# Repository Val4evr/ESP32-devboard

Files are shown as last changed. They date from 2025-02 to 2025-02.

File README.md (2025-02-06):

# ESP32-devboard

I made this ESP-32 Development board to learn KiCad. It is heavilly based on the [ESP32-DevKit C](https://www.espressif.com/en/products/devkits/esp32-devkitc/resources) reference implementation, but with the redundant micro USB port replaced with USB-C. Here's a ray-traced KiCad render:

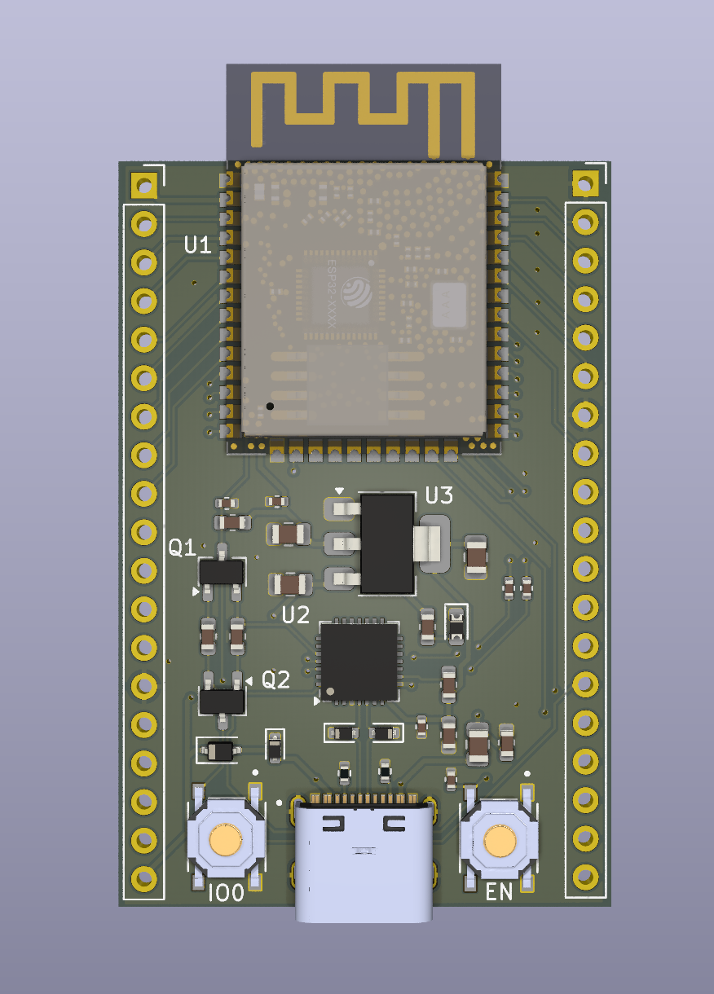
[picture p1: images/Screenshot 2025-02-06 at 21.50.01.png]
Ray-traced render of the assembled Devboard


# Usage
This repo comes with the footprints, 3D models and everything needed to reproduce the renders. Also, this KiCad project uses the [KiKit](https://github.com/yaqwsx/KiKit) extension to create the below panelization in a format compatible with the [JLCPCB PCBA service](https://jlcpcb.com/smt-assembly). 

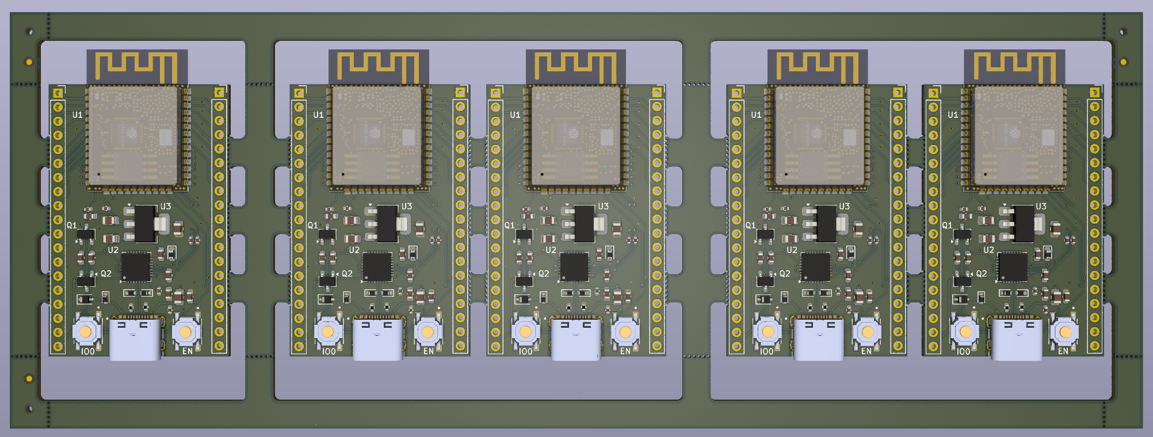
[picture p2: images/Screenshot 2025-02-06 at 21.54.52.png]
Ray-traced render of the assembled Devboards, panelized


The resultant production files are [here](https://github.com/Val4evr/ESP32-devboard/blob/main/ESP32_panelized_outputgerbers.zip). If you want to edit the design you will have to re-create the panel and gerbers for production:
1. [Setup KiKit](https://yaqwsx.github.io/KiKit/latest/installation/intro/)
2. Open an empty KiCad pcbnew instance
3. Click on the KiKit icon to open the GUI.
4. Select the updated pcb design and output directory (I used `/panelized`) 
5. Import my KiKit [JSON config](https://github.com/Val4evr/ESP32-devboard/blob/main/panelized/kikit_config.json)
6. Panelize!

If you then decide it's good enough for production, run the following snippet to get the gerbers, specifying the path to the panel. 
```
kikit fab jlcpcb --nametemplate "ESP32_panelized_output{}" --no-drc --assembly --schematic <path to schematic file> <path to PCB file> <path to output directory>
```

This will produce gerber, drill and position files for JLC PCB. 

# Previous revisions:
The PCB did not work on first try because of two misconfigured 0ohm DNP resistors on the USB serial traces. As a result I had to solder two strands of solder wick directly to the serial converter chip and ESP32, and hold them in place with copious quantities of tape. 

All Photos - 1 of 1

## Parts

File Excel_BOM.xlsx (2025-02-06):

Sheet: BOM
Simple Components:
Type | Comment / Value | Designator | Footprint / Package | JLCPCB Part# | Library Type (Ex/Exp/Bc) | Notes:
Capacitor | 4.7uF/16v(10%) | C1 | 0603 | C19666 | Basic
Capacitor | 0.1uF/50V(10%) | C2, C4, C5, C7, C9 | 0402 | C307331 | Basic
Capacitor | 22uF/10V(20%) | C3, C6, C8 | 0805 | C45783 | Basic
Resistor | 10K(5%) | R1, R2 | 1206 | C17902 | Basic
Resistor | 22K(5%) | R3 | 0805 | C17560 | Basic | Changed from 22.1K
Resistor | 47K(5%) | R4 | 0603 | C25819 | Basic | Changed from 44.5K.
Resistor | 2K(5%) | R5, R10 | 0603 | C22975 | Basic
Resistor | 0R (5%) | R6, R7 | 0402 | C17168 | Basic | 0 ohm resistor. Verify is required.
Resistor | 10K(1%) | R8, R9, R11, R12, R13, R14 | 0603 | C25804 | Basic | R8 is marked as NC. Verify.
Transistor | SS8050-G | Q1, Q2 | SOT23 | C164885 | External
ESD Protection | LESD5D5.OCT1G | D2, D3, D4 | SOD-523 | C383211 | External
Diode | BAT760-7 | D5 | SOD-323 | C124187 | External
LED | RED LED | D1 | 0603 | C2286 | Basic
Voltage Regulator | AMS1117-3.3 | U3 | SOT-223-3 | C6186 | Basic
Switch | TS-1187A-B-A-B | SW1, SW2 | SMD | C318884 | External
Complex Components:
Type | Comment / Value | Designator | Footprint / Package | JLCPCB Part# | Library Type (Ex/Exp/Bc) | Notes: | e
USB-C | 16Pin USB-C Connector | J3 | SMD | C2988369 | External
ESP32 | ESP32-WROOM-32E-N4 | U1 | SMD,18x25.5mm | C701341 | External
USB-UART | CP2102N-A02 | U2 | QFN-28-EP(5x5) | C964632 | External

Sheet: Formated BOM
Type | Comment | Designator | Footprint | JLCPCB Part#
Capacitor | 4.7uF/16v(10%) | C1 | 0603 | C19666
Capacitor | 0.1uF/50V(10%) | C2, C4, C5, C7, C9 | 0402 | C307331
Capacitor | 22uF/10V(20%) | C3, C6, C8 | 0805 | C45783
Resistor | 22K(5%) | R3 | 0805 | C17560
Resistor | 47K(5%) | R4 | 0603 | C25819
Resistor | 2K(5%) | R5, R10 | 0603 | C22975
Resistor | 0R (5%) | R6, R7 | 0402 | C17168 | e
Resistor | 10K(1%) | R1, R2, R8, R9, R11, R12, R13, R14 | 0603 | C25804
Transistor | SS8050-G | Q1, Q2 | SOT23 | C164885
ESD Protection | LESD5D5.OCT1G | D2, D3, D4 | SOD-523 | C383211
Diode | BAT760-7 | D5 | SOD-323 | C124187
LED | RED LED | D1 | 0603 | C2286
Voltage Regulator | AMS1117-3.3 | U3 | SOT-223-3 | C6186
Switch | TS-1187A-B-A-B | SW1, SW2 | SMD | C318884
USB-C | 16Pin USB-C Connector | J3 | SMD | C2988369
ESP32 | ESP32-WROOM-32E-N4 | U1 | SMD,18x25.5mm | C701341
USB-UART | CP2102N-A02 | U2 | QFN-28-EP(5x5) | C964632

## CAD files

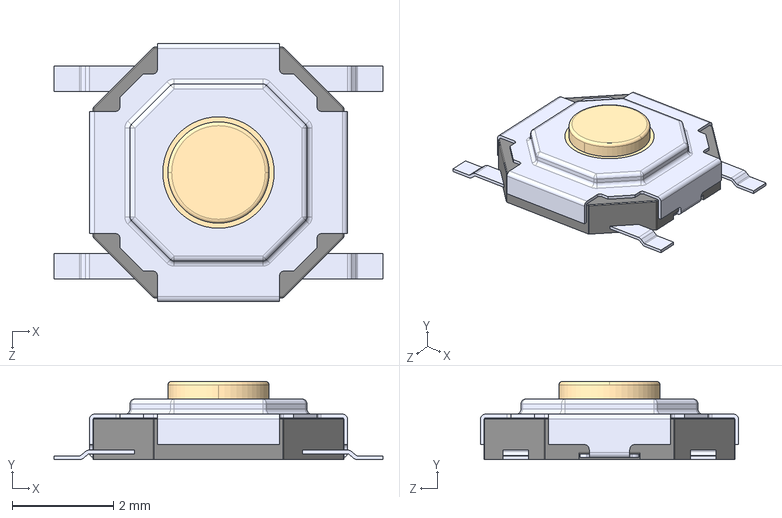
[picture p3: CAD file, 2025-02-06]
3D_models/TS-1187A-B-A-B--3DModel-STEP-56544.STEP
6.50 x 1.55 x 5.10 mm

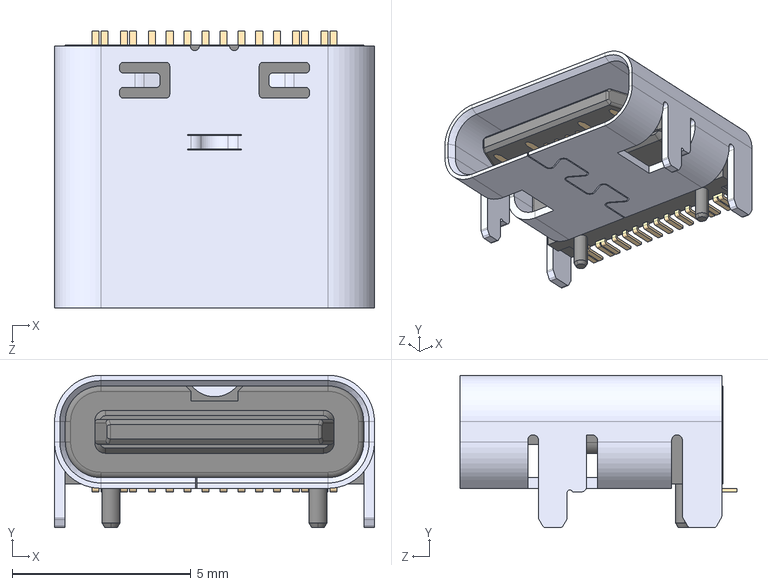
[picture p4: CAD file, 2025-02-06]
3D_models/CSP-USC16-TR--3DModel-STEP-468060.STEP
8.94 x 4.26 x 7.75 mm

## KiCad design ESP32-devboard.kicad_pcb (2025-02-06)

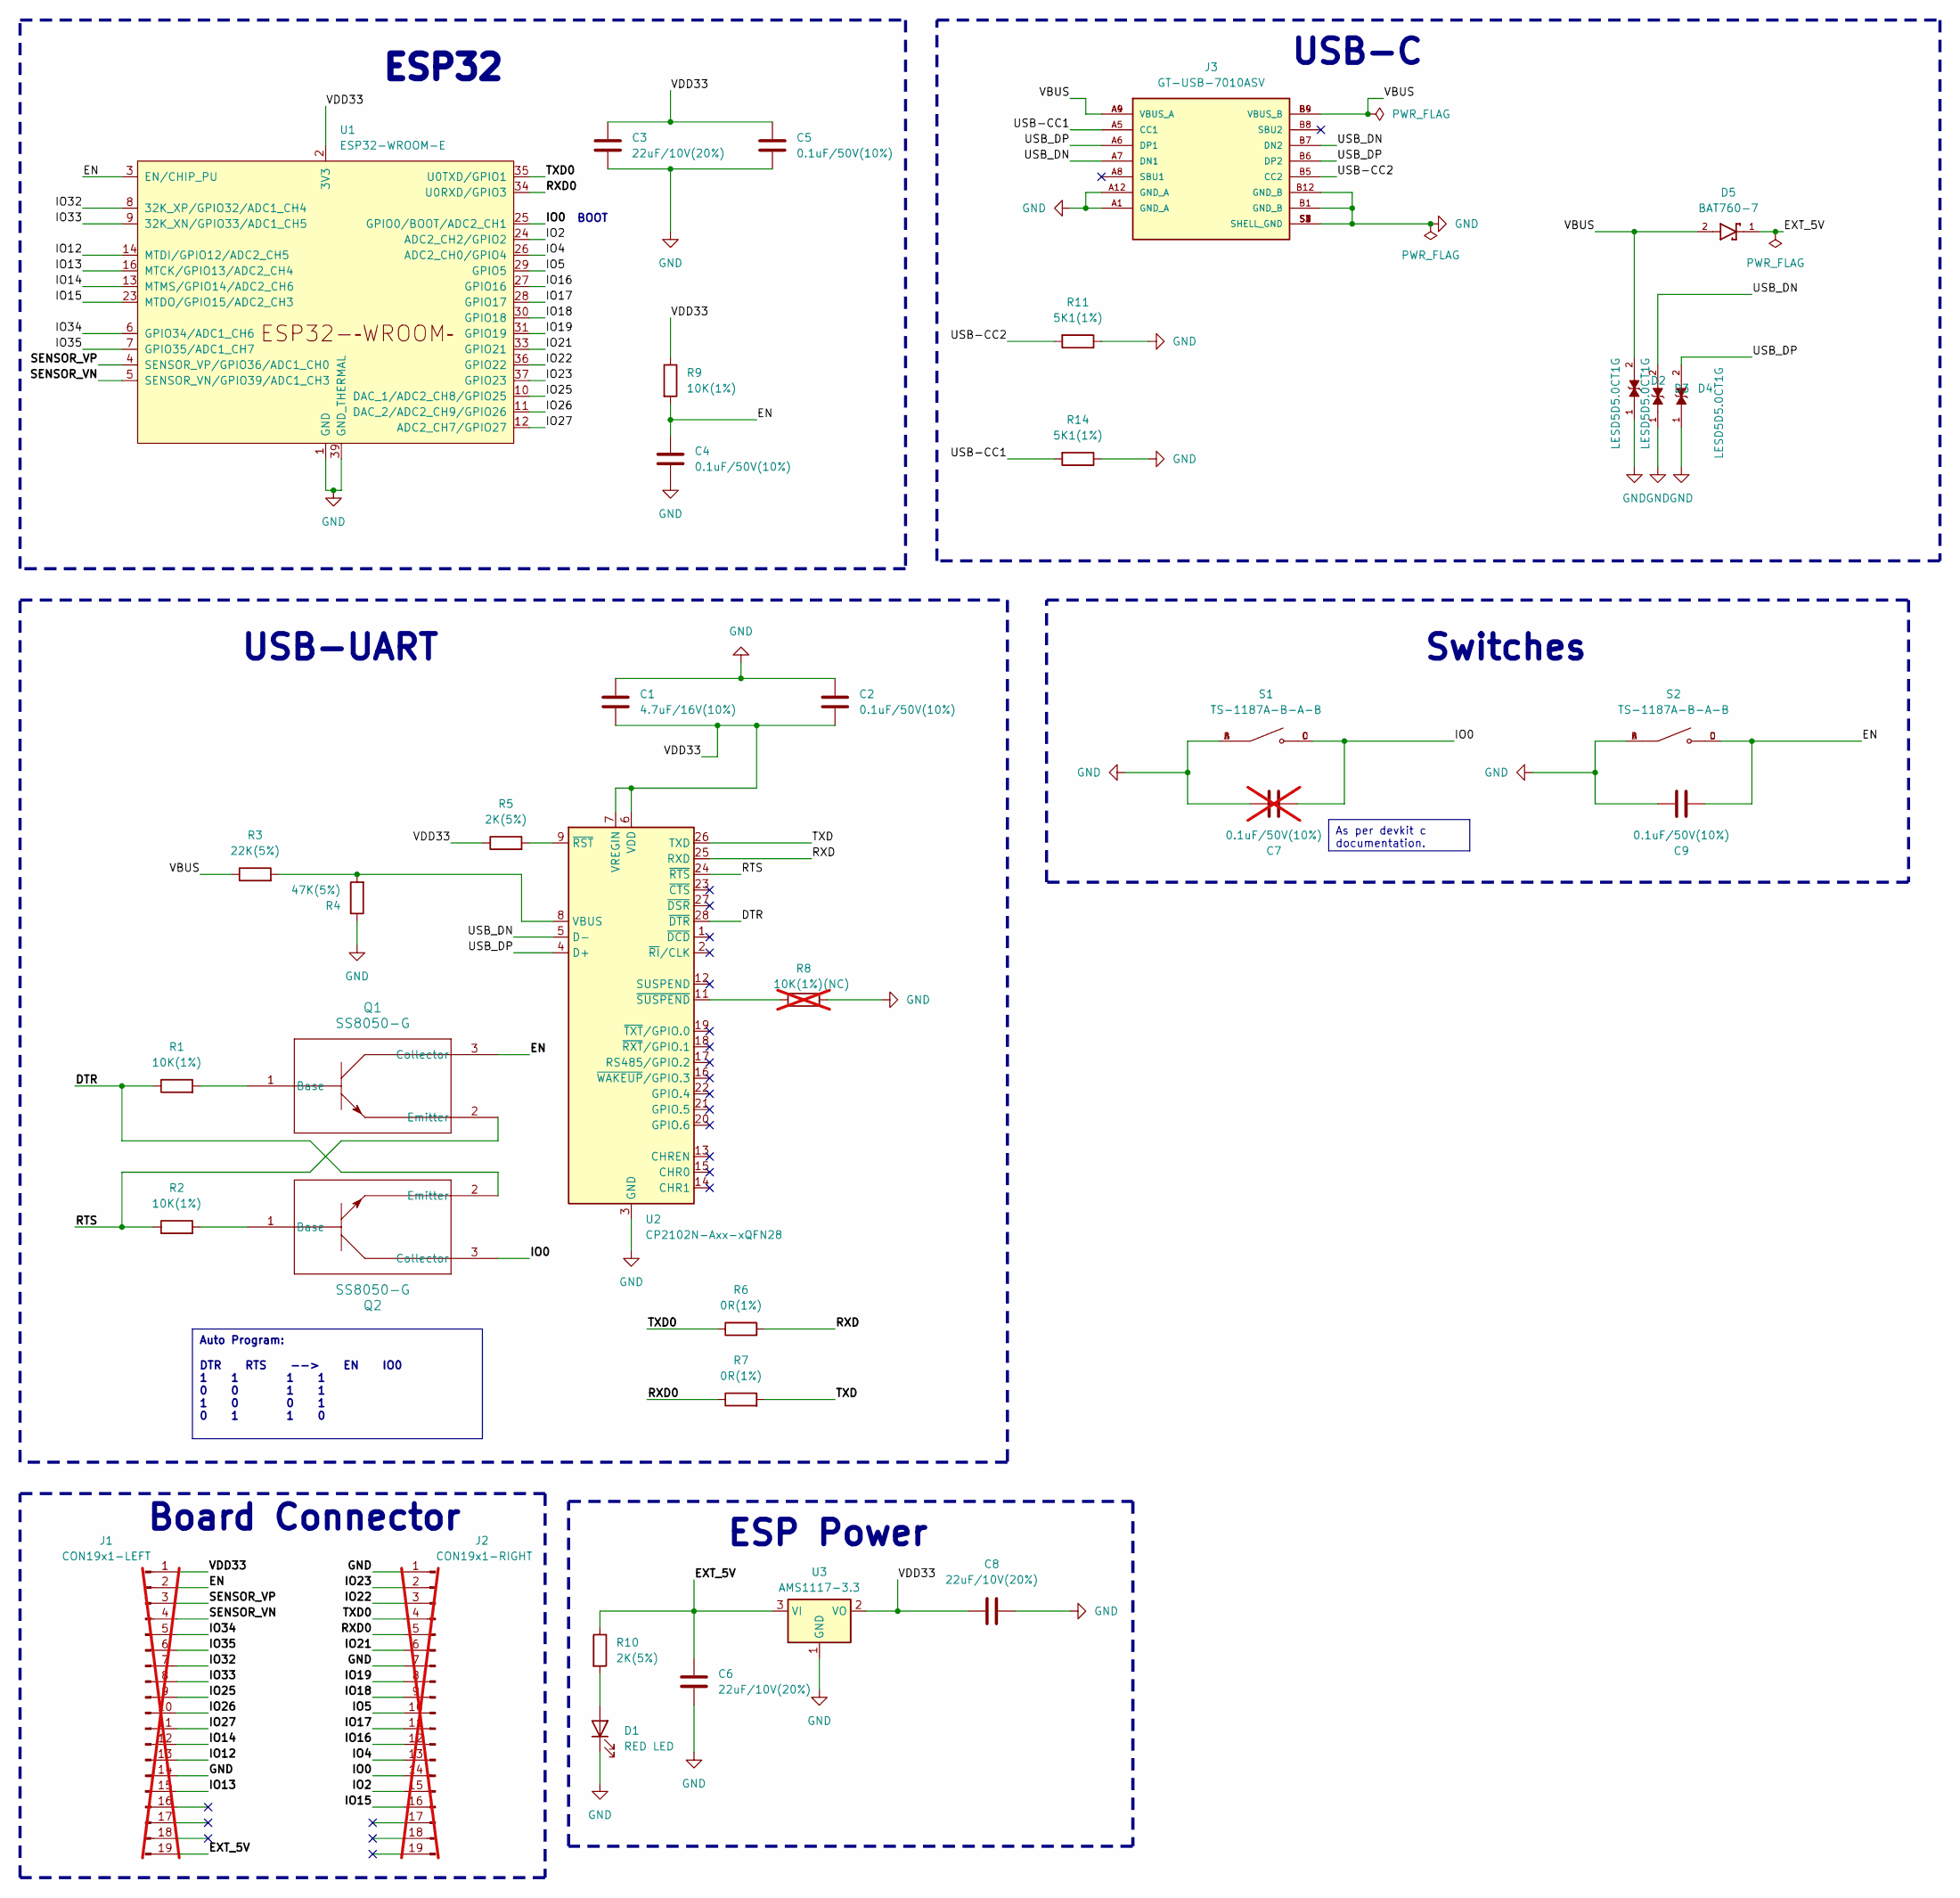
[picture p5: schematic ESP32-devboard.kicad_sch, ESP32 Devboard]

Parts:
C1: 4.7uF/16V(10%); C_0603_1608Metric; LCSC C19666
C2, C4, C5, C9: 0.1uF/50V(10%); C_0402_1005Metric; LCSC C307331
C3, C6, C8: 22uF/10V(20%); C_0805_2012Metric; LCSC C45783
C7: 0.1uF/50V(10%); C_0402_1005Metric; LCSC C307331; not fitted
D1: RED LED; D_0603_1608Metric; LCSC C2286
D2, D3, D4: LESD5D5.0CT1G; D_SOD-523; LCSC C383211
D5: BAT760-7; D_SOD-323; LCSC C124187
J1: CON19x1-LEFT; PinSocket_1x19_P2.54mm_Vertical; not fitted
J2: CON19x1-RIGHT; PinSocket_1x19_P2.54mm_Vertical; not fitted
J3: GT-USB-7010ASV; GT-USB-7010; LCSC C2988369
Q1, Q2: SS8050-G; TSOT-23; LCSC C164885
R1, R2, R9: 10K(1%); C_0603_1608Metric; LCSC C25804
R3: 22K(5%); C_0805_2012Metric; LCSC C17560
R4: 47K(5%); C_0603_1608Metric; LCSC C25819
R5, R10: 2K(5%); C_0603_1608Metric; LCSC C22975
R6, R7: 0R(1%); C_0402_1005Metric; LCSC C17168
R8: 10K(1%)(NC); C_0603_1608Metric; LCSC C25804; not fitted
R11, R14: 5K1(1%); R_0402_1005Metric; LCSC C25905
S1, S2: TS-1187A-B-A-B; SW_TS-1187A-B-A-B; PARTREV A0; LCSC C318884
U1: ESP32-WROOM-E; ESP32-WROOM-32E; LCSC C701341
U2: CP2102N-Axx-xQFN28; QFN-28-1EP_5x5mm_P0.5mm_EP3.35x3.35mm; LCSC C964632
U3: AMS1117-3.3; SOT-223-3_TabPin2; LCSC C6186

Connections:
/DTR: Q2.2 (Emitter), R1.1, U2.28 (~DTR)
/EN: C4.1, C9.1, J1.2, Q1.3 (Collector), R9.2, S2.C, S2.D, U1.3 (EN/CHIP_PU)
/EXT_5V: C6.1, D5.1, J1.19, R10.1, U3.3 (VI)
/IO0: C7.1, J2.14, Q2.3 (Collector), S1.C, S1.D, U1.25 (GPIO0/BOOT/ADC2_CH1)
/IO2: J2.15, U1.24 (ADC2_CH2/GPIO2)
/IO4: J2.13, U1.26 (ADC2_CH0/GPIO4)
/IO5: J2.10, U1.29 (GPIO5)
/IO12: J1.13, U1.14 (MTDI/GPIO12/ADC2_CH5)
/IO13: J1.15, U1.16 (MTCK/GPIO13/ADC2_CH4)
/IO14: J1.12, U1.13 (MTMS/GPIO14/ADC2_CH6)
/IO15: J2.16, U1.23 (MTDO/GPIO15/ADC2_CH3)
/IO16: J2.12, U1.27 (GPIO16)
/IO17: J2.11, U1.28 (GPIO17)
/IO18: J2.9, U1.30 (GPIO18)
/IO19: J2.8, U1.31 (GPIO19)
/IO21: J2.6, U1.33 (GPIO21)
/IO22: J2.3, U1.36 (GPIO22)
/IO23: J2.2, U1.37 (GPIO23)
/IO25: J1.9, U1.10 (DAC_1/ADC2_CH8/GPIO25)
/IO26: J1.10, U1.11 (DAC_2/ADC2_CH9/GPIO26)
/IO27: J1.11, U1.12 (ADC2_CH7/GPIO27)
/IO32: J1.7, U1.8 (32K_XP/GPIO32/ADC1_CH4)
/IO33: J1.8, U1.9 (32K_XN/GPIO33/ADC1_CH5)
/IO34: J1.5, U1.6 (GPIO34/ADC1_CH6)
/IO35: J1.6, U1.7 (GPIO35/ADC1_CH7)
/RTS: Q1.2 (Emitter), R2.1, U2.24 (~RTS)
/RXD: R6.2, U2.25 (RXD)
/RXD0: J2.5, R7.1, U1.34 (U0RXD/GPIO3)
/SENSOR_VN: J1.4, U1.5 (SENSOR_VN/GPIO39/ADC1_CH3)
/SENSOR_VP: J1.3, U1.4 (SENSOR_VP/GPIO36/ADC1_CH0)
/TXD: R7.2, U2.26 (TXD)
/TXD0: J2.4, R6.1, U1.35 (U0TXD/GPIO1)
/USB-CC1: J3.A5 (CC1), R14.2
/USB-CC2: J3.B5 (CC2), R11.2
/USB_DN: D3.2, J3.A7 (DN1), J3.B7 (DN2), U2.5 (D-)
/USB_DP: D4.2, J3.A6 (DP1), J3.B6 (DP2), U2.4 (D+)
/VBUS: D2.2, D5.2, J3.A4 (VBUS_A), J3.A9 (VBUS_A), J3.B4 (VBUS_B), J3.B9 (VBUS_B), R3.1
/VDD33: C1.2, C2.2, C3.1, C5.1, C8.1, J1.1, R5.1, R9.1, U1.2 (3V3), U2.6 (VDD), U2.7 (VREGIN), U3.2 (VO)
GND: C1.1, C2.1, C3.2, C4.2, C5.2, C6.2, C7.2, C8.2, C9.2, D1.1 (K), D2.1, D3.1, D4.1, J1.14, J2.1, J2.7, J3.A1 (GND_A), J3.A12 (GND_A), J3.B1 (GND_B), J3.B12 (GND_B), J3.S1 (SHELL_GND), J3.S2 (SHELL_GND), J3.S3 (SHELL_GND), J3.S4 (SHELL_GND), R4.1, R8.2, R11.1, R14.1, S1.A, S1.B, S2.A, S2.B, U1.1 (GND), U1.15 (GND), U1.38 (GND), U1.39 (GND_THERMAL), U2.3 (GND), U2.29 (GND), U3.1 (GND)
unnamed: D1.2 (A), R10.2
unnamed: Q1.1 (Base), R1.2
unnamed: Q2.1 (Base), R2.2
unnamed: R3.2, R4.2, U2.8 (VBUS)
unnamed: R5.2, U2.9 (~RST)
unnamed: R8.1, U2.11 (~SUSPEND)

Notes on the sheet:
Auto Program: DTR RTS --> EN IO0 1 1 1 1 0 0 1 1 1 0 0 1 0 1 1 0
As per devkit c documentation.
ESP Power
Board Connector
Switches
USB-C
ESP32
BOOT
USB-UART

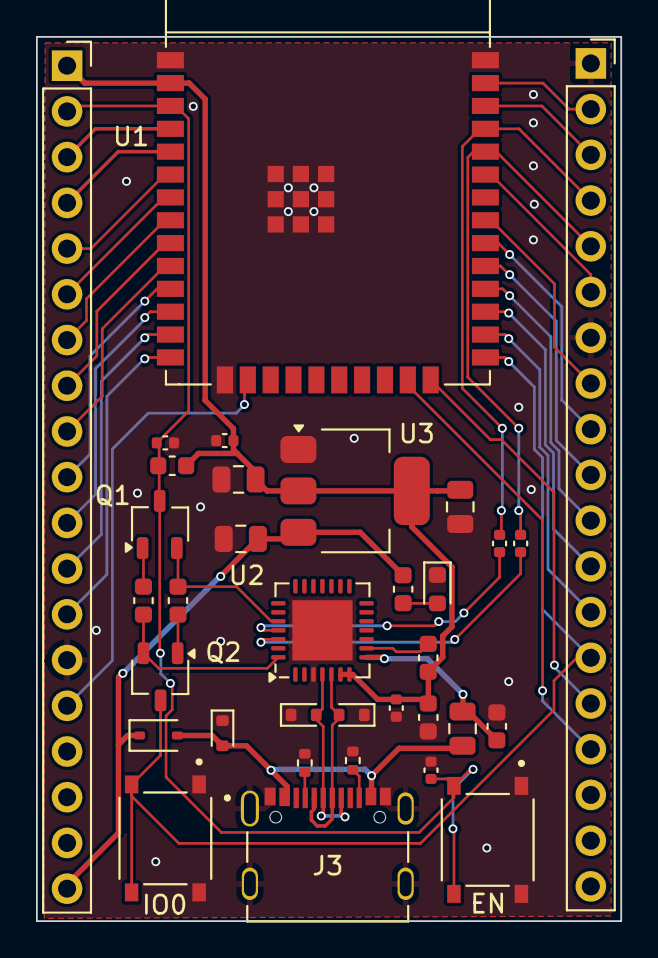
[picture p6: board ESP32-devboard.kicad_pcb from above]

Board: 2 copper layers, 32.5 x 49.1 mm, 34 parts (0 on the bottom side), 44 nets.
